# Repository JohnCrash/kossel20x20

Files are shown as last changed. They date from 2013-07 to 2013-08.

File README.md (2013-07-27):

<<<<<<< HEAD
Release status
==============

Most of these parts are now stable and won't change much more.

How to print Mini Kossel
========================

* 3x plate_3x.stl (about 3x80g = 240g of plastic)
* 1x plate_1x.stl (about 50g of plastic)

Links
=====

* Bill of Materials: http://reprap.org/wiki/Kossel
* Mailing list: http://groups.google.com/group/deltabot
* Project history: http://deltabot.tumblr.com

Pay it forward
==============

Johann is offering free printed parts for Mini Kossel:

* I'm going to make some Mini Kossel printed parts kits.
* I'm going to give them away for free (as in beer).
* Some kits may include some non-printed parts.
* Free international shipping is included.
* No delivery schedule, maybe only one kit per month.

But there's no such thing as a free lunch. If you want to receive a
free kit, you must swear by your geek honor:

* To complete your Mini Kossel and tune it well.
* To print two (2) Mini Kossel kits and also give them away for free.
* To make your recipients agree to the same rule.

After giving away the 2 free kits, you may sell printed parts for any
price you want.

If you're interested, please email johann@rocholl.net and let me know
your favorite PLA color and mailing address. If you want to get your
printed parts first, explain why you're more qualified than others to
start giving away high quality printed parts soon.
=======
kossel20x20
===========

scad source
>>>>>>> cce76dabf2352457aa02cc0f23a5b00312168b90

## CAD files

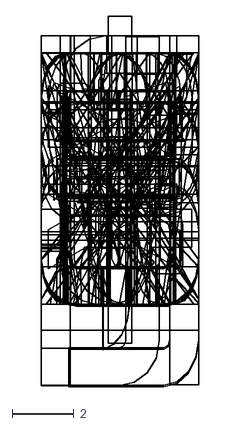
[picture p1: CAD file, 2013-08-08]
orbitron.dxf
5.08 x 12.0

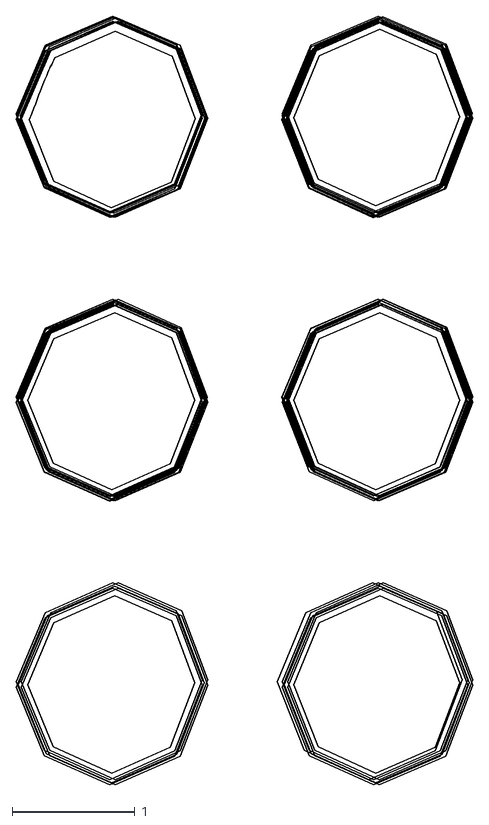
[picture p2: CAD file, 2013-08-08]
braille.dxf
3.72 x 6.26

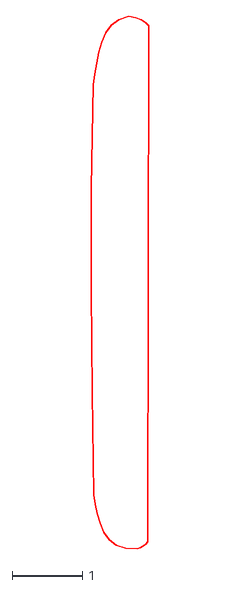
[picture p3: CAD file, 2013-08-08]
1.dxf
0.819 x 7.58

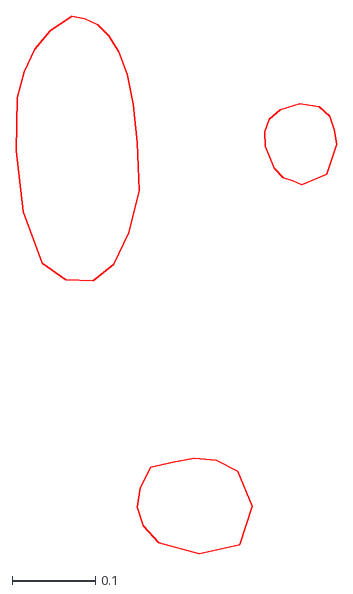
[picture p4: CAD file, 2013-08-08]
4.dxf
0.386 x 0.647

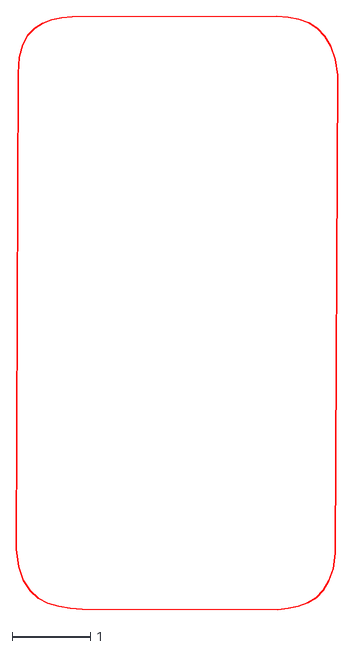
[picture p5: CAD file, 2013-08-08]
3.dxf
4.09 x 7.56

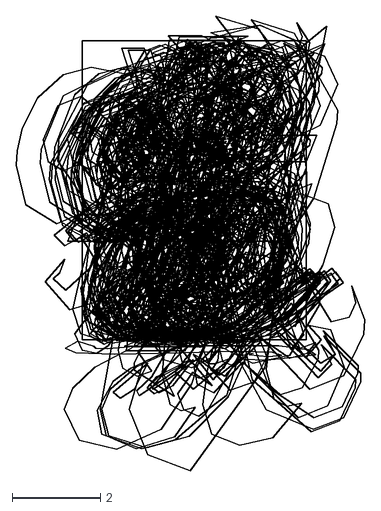
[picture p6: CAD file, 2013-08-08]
BlackRose.dxf
7.90 x 10.3

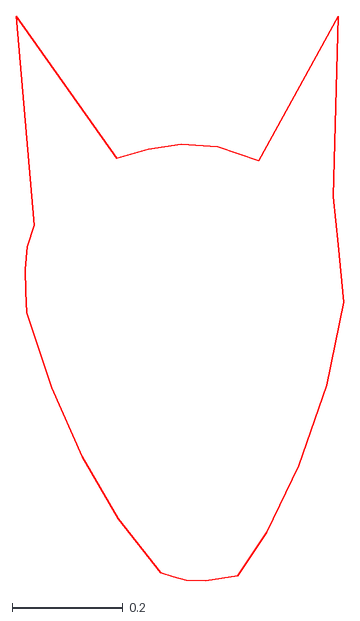
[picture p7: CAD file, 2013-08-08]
5.dxf
0.592 x 1.02

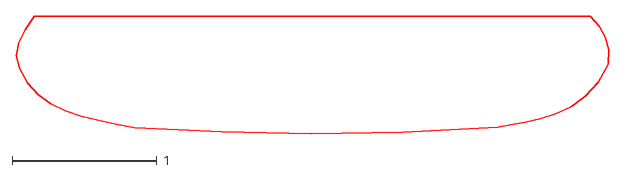
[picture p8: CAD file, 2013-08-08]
2.dxf
4.10 x 0.81

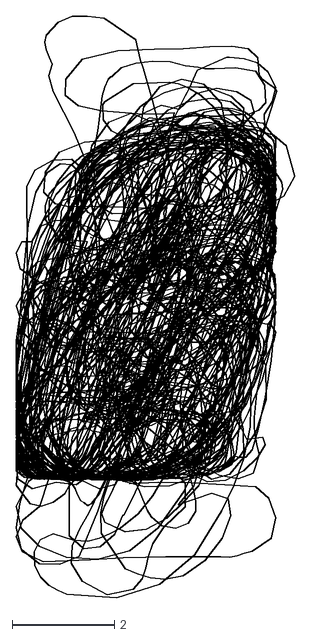
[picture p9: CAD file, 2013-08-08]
knewave.dxf
5.46 x 11.4

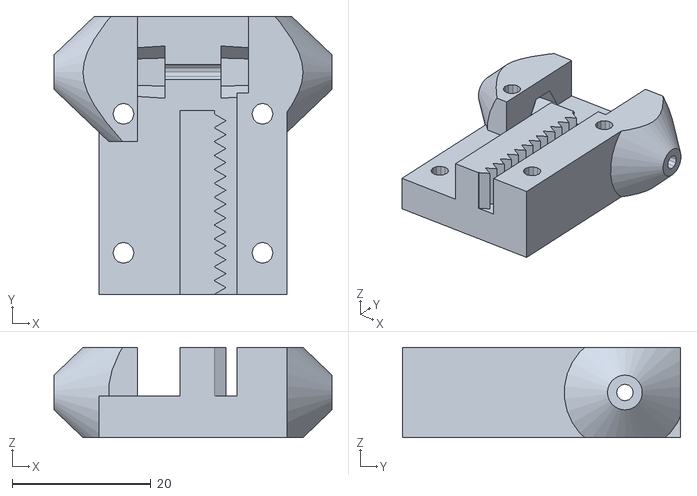
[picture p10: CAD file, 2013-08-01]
carriage.stl
40.0 x 40.0 x 13.0

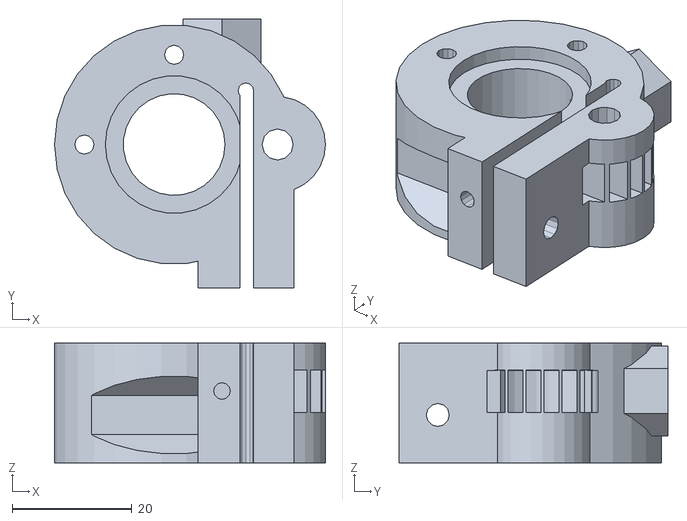
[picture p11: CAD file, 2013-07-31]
extruder.stl
45.3 x 45.0 x 20.0

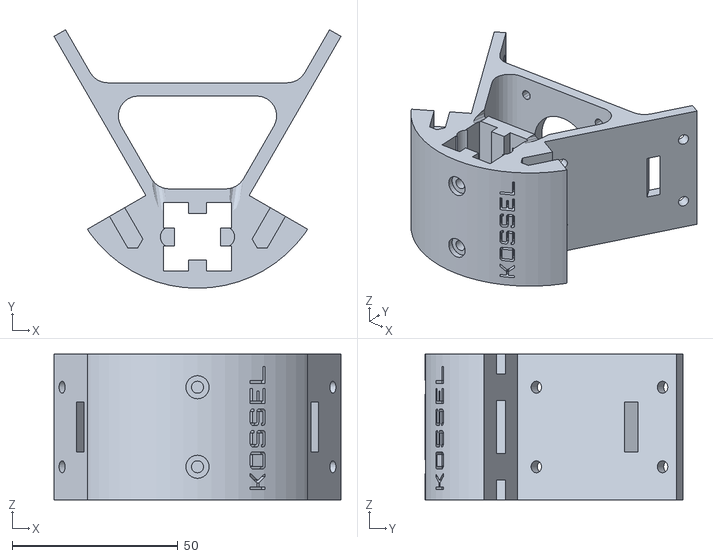
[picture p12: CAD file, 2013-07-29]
frame_motor.stl
86.6 x 78.0 x 44.0

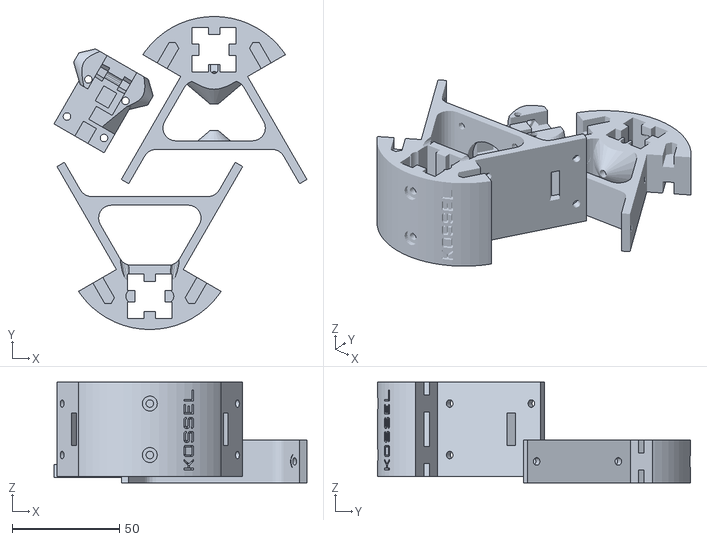
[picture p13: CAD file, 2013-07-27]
plate_3x.stl
118.0 x 146.0 x 47.0

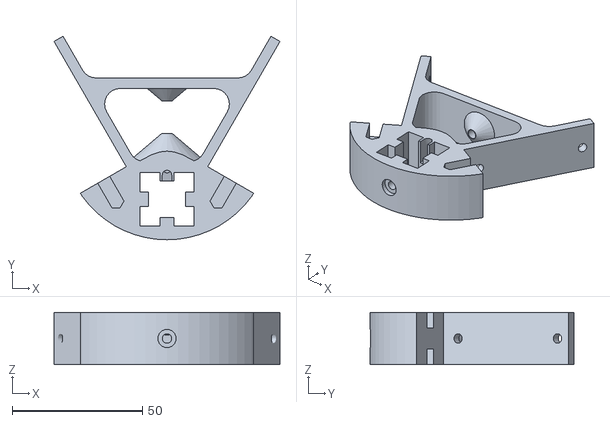
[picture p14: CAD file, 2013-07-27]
frame_top.stl
86.6 x 78.0 x 20.0

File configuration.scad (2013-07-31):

// Increase this if your slicer or printer make holes too tight.
extra_radius = 0.30;

// OD = outside diameter, corner to corner.
//六角螺母
m3_nut_od = 6.1;
m3_nut_radius = m3_nut_od/2 + 0.2 + extra_radius;
m4_nut_od = 8;
m4_nut_radius = m4_nut_od/2 + 0.2 +extra_radius;
m3_nut_height = 2.4;
m4_nut_height = 3.2;

// Major diameter of metric 3mm thread.
m3_major = 2.85;
m3_radius = m3_major/2 + extra_radius;
m3_wide_radius = m3_major/2 + extra_radius + 0.2;

// NEMA17 stepper motors.
motor_shaft_diameter = 5;
motor_shaft_radius = motor_shaft_diameter/2 + extra_radius;

// Frame brackets. M3x8mm screws work best with 3.6 mm brackets.
thickness = 3.6;

// OpenBeam or Misumi. Currently only 15x15 mm, but there is a plan
// to make models more parametric and allow 20x20 mm in the future.
//extrusion = 15;
extrusion = 20;
//extrusion_block_width = 2.5; //15x15
extrusion_block_width = 6.1; //20x20

//corner_radius = 36; //15x15
corner_radius = 40; //20x20

//extrusion_offset = 0;//15x15
extrusion_offset = -2.5; //20x20

//height_offset = 0; //15x15
height_offset = -extrusion_offset; //20x20

//screw_offset=-7.5; //15x15
screw_offset=-12; //20x20

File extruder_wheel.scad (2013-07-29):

//默认使用外径17的轴承
module extruder_wheel(r=16/2)
{
	//轴承
	translate([-r-17/2-1.75/2,0,3])
	difference()
	{
		cylinder(r=17/2,h=6,center=true);
		cylinder(r=3,h=6,center=true);
	}
	
	//挤出齿
	difference()
	{
		cylinder(r=r,h=18,center=true);
		cylinder(r=4,h=18,center=true);
		#translate([0,0,3])difference()
		{
			cylinder(r=r,h=2,center=true);
			cylinder(r=r-0.6,h=2,center=true);
		}
	}
	
	//丝线
	#translate([-r,30,3])
	rotate([90,0,0])
	cylinder(r=1.75/2,h=60,$fn=8);
}

extruder_wheel(8);

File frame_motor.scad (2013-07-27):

include <configuration.scad>;

use <vertex.scad>;

$fn = 24;
motor_offset = 44;
motor_length = 47;

module frame_motor() {
  difference() {
    // No idler cones.
    vertex(2.2*extrusion, idler_offset=0, idler_space=100);
    // KOSSEL logotype.
    translate([20.5, -10-2.5, 0]) rotate([90, -90, 30])
      scale([0.11, 0.11, 1]) import("logotype.stl");
    // Motor cable paths.
    for (mirror = [-1, 1]) scale([mirror, 1, 1]) {
      translate([-35, 45, 0]) rotate([0, 0, -30])
        # cube([4, 15, 15], center=true);
      translate([-8, -2.5, 0]) cylinder(r=3.2, h=40);
      translate([-11, -2.5, 0]) # cube([15, 6.4, 15], center=true);
    }
    translate([0, motor_offset, 0]) {
      // Motor shaft/pulley cutout.
      rotate([90, 0, 0]) cylinder(r=12, h=20, center=true, $fn=60);
      // NEMA 17 stepper motor mounting screws.
      for (x = [-1, 1]) for (z = [-1, 1]) {
        scale([x, 1, z]) translate([15.5, -5, 15.5]) {
          rotate([90, 0, 0]) cylinder(r=1.65, h=20, center=true, $fn=12);
          // Easier ball driver access.
          rotate([74, -30, 0]) # cylinder(r=1.8, h=60, $fn=12);
        }
      }
    }
  }
  // NEMA 17 stepper motor.
  % translate([0, motor_offset + motor_length/2, 0]) intersection() {
    cube([42.2, motor_length, 42.2], center=true);
    rotate([0, 45, 0]) cube([52, motor_length, 52], center=true);
  }
}

//projection(cut=true) 
translate([0, 0, 0]) frame_motor();

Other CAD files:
Letters.dxf
all.scad
Write.scad
carriage.scad
cas.scad
catcher.scad
effector.scad
effector2.scad
effector3.scad
effector4.scad
ej.scad
endstop_new.scad
extruder.scad
fan_zj.scad
iphone3g.scad
mixbot.scad
nozzel2.scad
nozzle.scad
plate_3x.scad
power_frame.scad
ramp_frame.scad
rod.scad
spring.scad
test.scad
text2d.scad
vertex.scad
wire_zj.scad
wire_zj2.scad
wire_zj3.scad

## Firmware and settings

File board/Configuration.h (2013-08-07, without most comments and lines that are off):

#define CONFIGURATION_H
#define STRING_VERSION_CONFIG_H __DATE__ " " __TIME__ // build date and time
#define STRING_CONFIG_H_AUTHOR "(none, default config)" //Who made the changes.
#define SERIAL_PORT 0
#define BAUDRATE 250000
#define MOTHERBOARD 70
#define TEMP_SENSOR_0 1
#define TEMP_SENSOR_1 0
#define TEMP_SENSOR_2 0
#define TEMP_SENSOR_BED 1
#define TEMP_RESIDENCY_TIME 10	// (seconds)
#define TEMP_HYSTERESIS 3       // (degC) range of +/- temperatures considered "close" to the target one
#define TEMP_WINDOW     1       // (degC) Window around target to start the recidency timer x degC early.
#define HEATER_0_MINTEMP 5
#define HEATER_1_MINTEMP 5
#define HEATER_2_MINTEMP 5
#define BED_MINTEMP 5
#define HEATER_0_MAXTEMP 275
#define HEATER_1_MAXTEMP 275
#define HEATER_2_MAXTEMP 275
#define BED_MAXTEMP 150
#define PIDTEMP
#define PID_MAX 255 // limits current to nozzle; 255=full current
  #define PID_INTEGRAL_DRIVE_MAX 255  //limit for the integral term
  #define K1 0.95 //smoothing factor withing the PID
  #define PID_dT ((16.0 * 8.0)/(F_CPU / 64.0 / 256.0)) //sampling period of the
    #define  DEFAULT_Kp 22.2
    #define  DEFAULT_Ki 1.08
    #define  DEFAULT_Kd 114
#define MAX_BED_POWER 255 // limits duty cycle to bed; 255=full current
#define PREVENT_DANGEROUS_EXTRUDE
#define PREVENT_LENGTHY_EXTRUDE
#define EXTRUDE_MINTEMP 170
#define EXTRUDE_MAXLENGTH (X_MAX_LENGTH+Y_MAX_LENGTH) //prevent extrusion of very large distances.
#define ENDSTOPPULLUPS // Comment this out (using // at the start of the line) to disable the endstop pullup resistors
  #define ENDSTOPPULLUP_XMAX
  #define ENDSTOPPULLUP_YMAX
  #define ENDSTOPPULLUP_ZMAX
  #define ENDSTOPPULLUP_XMIN
  #define ENDSTOPPULLUP_YMIN
  #define ENDSTOPPULLUP_ZMIN
const bool X_ENDSTOPS_INVERTING = true; // set to true to invert the logic of the endstops.
const bool Y_ENDSTOPS_INVERTING = true; // set to true to invert the logic of the endstops.
const bool Z_ENDSTOPS_INVERTING = true; // set to true to invert the logic of the endstops.
#define X_ENABLE_ON 0
#define Y_ENABLE_ON 0
#define Z_ENABLE_ON 0
#define E_ENABLE_ON 0 // For all extruders
#define DISABLE_X false
#define DISABLE_Y false
#define DISABLE_Z false
#define DISABLE_E false // For all extruders
#define INVERT_X_DIR true    // for Mendel set to false, for Orca set to true
#define INVERT_Y_DIR false    // for Mendel set to true, for Orca set to false
#define INVERT_Z_DIR true     // for Mendel set to false, for Orca set to true
#define INVERT_E0_DIR true   // for direct drive extruder v9 set to true, for geared extruder set to false
#define INVERT_E1_DIR false    // for direct drive extruder v9 set to true, for geared extruder set to false
#define INVERT_E2_DIR false   // for direct drive extruder v9 set to true, for geared extruder set to false
#define X_HOME_DIR -1
#define Y_HOME_DIR -1
#define Z_HOME_DIR -1
#define min_software_endstops true //If true, axis won't move to coordinates less than HOME_POS.
#define max_software_endstops true  //If true, axis won't move to coordinates greater than the defined lengths below.
#define X_MAX_POS 205
#define X_MIN_POS 0
#define Y_MAX_POS 205
#define Y_MIN_POS 0
#define Z_MAX_POS 200
#define Z_MIN_POS 0
#define X_MAX_LENGTH (X_MAX_POS - X_MIN_POS)
#define Y_MAX_LENGTH (Y_MAX_POS - Y_MIN_POS)
#define Z_MAX_LENGTH (Z_MAX_POS - Z_MIN_POS)
#define MANUAL_X_HOME_POS 0
#define MANUAL_Y_HOME_POS 0
#define MANUAL_Z_HOME_POS 0
#define NUM_AXIS 4 // The axis order in all axis related arrays is X, Y, Z, E
#define HOMING_FEEDRATE {50*60, 50*60, 4*60, 0}  // set the homing speeds (mm/min)
#define DEFAULT_AXIS_STEPS_PER_UNIT   {78.7402,78.7402,200*8/3,760*1.1}  // default steps per unit for ultimaker
#define DEFAULT_MAX_FEEDRATE          {500, 500, 5, 45}    // (mm/sec)
#define DEFAULT_MAX_ACCELERATION      {9000,9000,100,10000}    // X, Y, Z, E maximum start speed for accelerated moves. E default values are good for skeinforge 40+, for older versions raise them a lot.
#define DEFAULT_ACCELERATION          3000    // X, Y, Z and E max acceleration in mm/s^2 for printing moves
#define DEFAULT_RETRACT_ACCELERATION  3000   // X, Y, Z and E max acceleration in mm/s^2 for r retracts
#define DEFAULT_XYJERK                20.0    // (mm/sec)
#define DEFAULT_ZJERK                 0.4     // (mm/sec)
#define DEFAULT_EJERK                 5.0    // (mm/sec)
#define ULTIMAKERCONTROLLER //as available from the ultimaker online store.
 #define ULTIPANEL
 #define NEWPANEL
#define PLA_PREHEAT_HOTEND_TEMP 180
#define PLA_PREHEAT_HPB_TEMP 70
#define PLA_PREHEAT_FAN_SPEED 255		// Insert Value between 0 and 255
#define ABS_PREHEAT_HOTEND_TEMP 240
#define ABS_PREHEAT_HPB_TEMP 100
#define ABS_PREHEAT_FAN_SPEED 255		// Insert Value between 0 and 255
  #define NEWPANEL  //enable this if you have a click-encoder panel
  #define SDSUPPORT
  #define ULTRA_LCD
  #define LCD_WIDTH 20
  #define LCD_HEIGHT 4
#include "Configuration_adv.h"
#include "thermistortables.h"

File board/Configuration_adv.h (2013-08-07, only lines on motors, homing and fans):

#define ENDSTOPS_ONLY_FOR_HOMING // If defined the endstops will only be used for homing
#define X_HOME_RETRACT_MM 5
#define Y_HOME_RETRACT_MM 5
#define Z_HOME_RETRACT_MM 1
#define MICROSTEP1 LOW,LOW
#define MICROSTEP2 HIGH,LOW
#define MICROSTEP4 LOW,HIGH
#define MICROSTEP8 HIGH,HIGH
#define MICROSTEP16 HIGH,HIGH
#define MICROSTEP_MODES {16,16,16,16,16} // [1,2,4,8,16]
#define DIGIPOT_MOTOR_CURRENT {185,185,185,185,135} // Values 0-255 (RAMBO 135 = ~0.75A, 185 = ~1A)

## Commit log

2013-07-27 support 20x20
    [configuration.scad, extruder.scad, extruder.stl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]
2013-07-29 motify exteruder
    [all.scad, cas.scad, extruder.scad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]
2013-07-31 exteruder motify
    [carriage.scad, configuration.scad, extruder.scad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]
2013-07-31 carrage motify
    [carriage.scad, extruder.scad, extruder.stl]
2013-07-31 carriage motify
    [carriage.scad]
2013-08-07 mega2560+ramps1.4 board driver and pin config
    [Configuration.h, Configuration_adv.h, Menu Plans.xlsx]
2013-08-07 board document
2013-09-16 电路板支架
    [effector4.scad, ej.scad, mixbot.scad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]
2014-07-04 update 11
    [catcher.scad, extruder.scad]
2014-07-07 风扇支架
    [fan_zj.scad]
2014-07-16 new wire_zj
    [wire_zj3.scad]
